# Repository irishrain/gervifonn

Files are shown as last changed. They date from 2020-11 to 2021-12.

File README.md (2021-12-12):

# gervifonn

The gervifonn is a device to access music stored in a digital music library by interacting with physical CD cases.
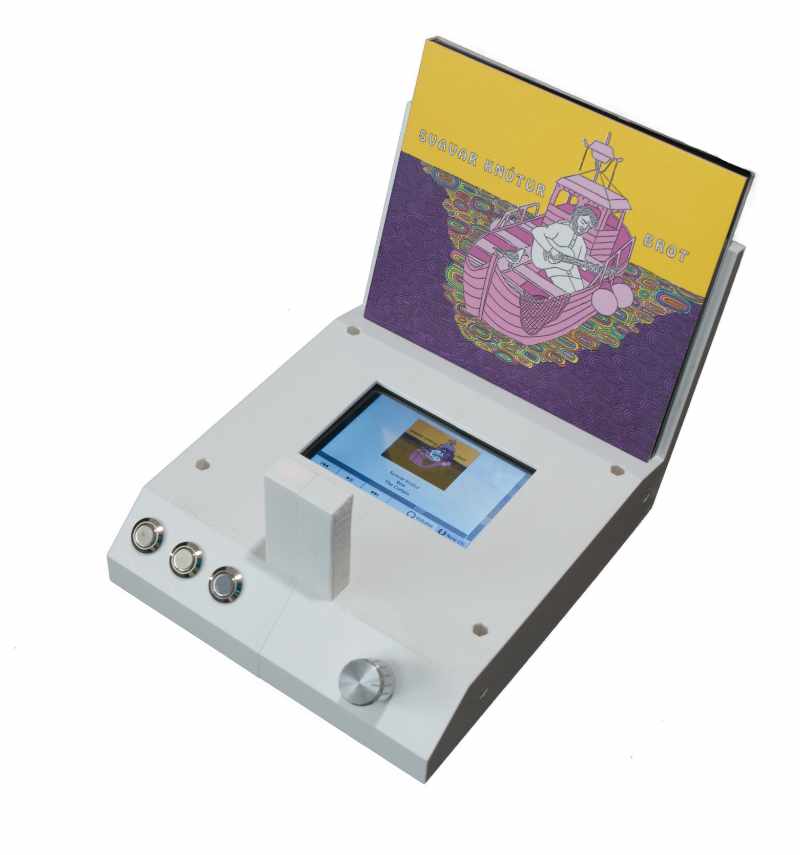
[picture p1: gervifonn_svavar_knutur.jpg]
Gervifonn Gervifonn with Brot by Svavar Knutur


## Features
The gervifonn displays the currently playing album. You can change the volume, pause playback or skip to the previous/next song. When you put a CD case onto the gervifonn and press the knob, it uses an AI to recognize the album you want to play.

### gervifonn in action

https://user-images.githubusercontent.com/74204581/131494693-2eaad112-3a38-4ad9-bd8d-b11cf11d26b1.mp4

https://user-images.githubusercontent.com/74204581/131494710-aeeac02b-b2e4-4ee5-975f-765dfd78c2d3.mp4

## Name
The name "gervifonn" derives from the icelandic words "gervigreind" (Artificial Intelligence) and "fónn" (Record Player).

## Assembly
See below for details of required parts and software. Assemble the gervifonn in the following order:
1. Install Raspberry Pi OS (Legacy) on micro SD card and put micro SD card into Raspberry Pi
2. Configure Rasberry Pi OS for automatic login, enable wifi, camera and ssh access and install the display drivers provided by the vendor
3. Install gervifonn software
4. Install pushbuttons, rotary encoder and knob
5. Connect camera cable to camera. Put together the right and left half of the case, fitting the camera into the camera holder and threading the power cord through the hole in the back of the case. Make a knot in the power cord as a strain relief. Use screws and nuts to secure
6. Use screws to fix Raspberry Pi on bottom part of the case
7. Connect the pushbuttons and the rotary encoder like this using the flat ribbon cable:
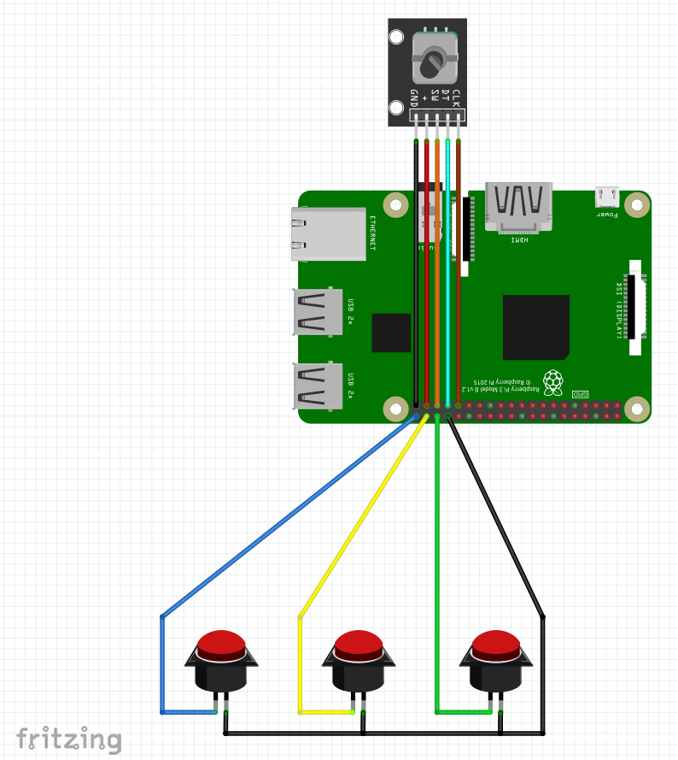
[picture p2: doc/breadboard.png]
Connections Breadboard view of required connections

6. Connect the camera cable to the Raspberry Pi and install display
7. Insert bottom part of case and secure with screws and nuts

## Components
### Case
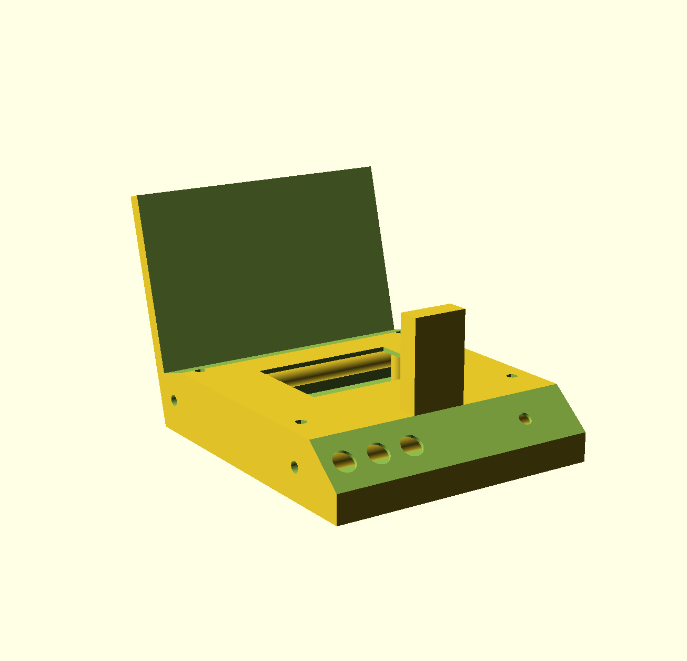
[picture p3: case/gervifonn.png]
Gervifonn case

The case is 3D printed. The [OpenSCAD](https://www.openscad.org/) source and generated STL files can be found under [case](case). The case is made from three parts, for assembly 12 M3 bolts and 8 M3 nuts are needed.
### Hardware
The heart of the gervifonn is a [Raspberry Pi 3 B+](https://www.raspberrypi.org/products/raspberry-pi-3-model-b-plus/).
Additionally the following parts were used (links to amazon.de, not sponsored):
* [Raspberry Pi Camera Revision 1.3](https://www.amazon.de/gp/product/B07CMXJLXR/) (use the long cable, not the 15cm one)
* [3.5 inch 320\*480 Resolution Touch Screen](https://www.amazon.de/gp/product/B01CNLYL1C/)
* [12mm pushbuttons](https://www.amazon.de/gp/product/B075YNQQ8J)
* [KY-040 Rotary Encoder](https://www.amazon.de/gp/product/B07CMVQHLT)
* [Knob for the Rotary Encoder](https://www.amazon.de/gp/product/B007JV6MAK)
* [10 Pin 2,54mm Pitch flat ribbon cable](https://www.amazon.de/gp/product/B07H9RQM5W/)
* A bit of extra wiring
* Micro-SD card
* Power supply for Raspberry Pi 3

### Software on the device
The gervifonn uses [Raspberry Pi OS](https://www.raspberrypi.org/software/) as a base.
The additional software running on the gervifonn can be found under [src](src). Install the requirements with `pip install -r requirements.txt` and place [src\gervifonn.desktop](src\gervifonn.desktop) into the /home/pi/.config/autostart/ directory of your raspberry. You might want to adapt the path to the gervifonn.py, the path to the music directory, the hostname of the [MPD](https://www.musicpd.org/) server, and the [Snapcast](https://github.com/badaix/snapcast) server and client if used.

### Software for training the AI
The AI-model needs to be trained on a more powerfull (linux) machine than a raspberry pi. A GPU with CUDA support is recommended, see [here](https://www.tensorflow.org/install/gpu#install_cuda_with_apt) for installation hints for the required libraries. Install the python libraries needed with `pip install -r training/requirements.txt`. To train the model use [training/train_gervifonn.py](training/train_gervifonn.py), with the path to your music folder and a folder with background images as arguments (details see below).
The resulting `gervifonn.tflite` model needs to be placed together with the generated `labels.txt` on your raspberry pi in the same folder as [src/gervifonn.py](src/gervifonn.py).

## Prerequesites
The gervifonn currently expects the following environment:
### Music library
The music library should be structured in the way [Jack](https://github.com/jack-cli-cd-ripper/jack) creates it, meaning one folder per Artist with subfolders for each album. Samplers are stored in the `Various` folder.

In addition, a cover image must be present in each folder, named `cover.png`. Optionally, you can place additional cover images in a subfolder called `gervifonn` inside each album. This will also be done by the gervifonn when you are using it. To simplify taking cover pictures of a bigger collection, you can use [src/gervifonn_capture_covers.py](src/gervifonn_capture_covers.py). Start it on the gervifonn, place the album on the gervifonn and press the leftmost button. It will take a picture in the correct format, display it and save it to the current folder. You can then put the next album on the gervifonn and press the leftmost button again. (Hint: use DISPLAY=:0 in front of the command when connected via ssh).

As albums with multiple CDs only have one cover, only place the `cover.png` in the first folder and create symlinks called `next` linking to the following CD.

To recap, here is an example folder structure:
~~~
Artist A
    Album 1
        gervifonn
            123.png
        cover.png
        Track X.ogg
        Track Y.ogg
        ...
    Album 2
        gervifonn
            456.png
            789.png
        cover.png
        Track I.ogg
        Track J.ogg
        ...
    ...
Artist B
    Album 1 CD 1
        gervifonn
            abc.png
        cover.png
        Track X.ogg
        ...
        next (symlink to ../Album 1 CD 2)
    Album 1 CD 2
        Track Y.ogg
        ...
...
~~~

### Music Player Daemon
The actual playback of the music is handled by the [Music Player Daemon](https://www.musicpd.org/). The MPD should be configured to read in your music library and should be reachable from the gervifonn (without authentification). If you don't have an extra machine, it should be fine to install the MPD on the gervifonn as well.

### Scnapcast
If the audio is streamed from the MPD via [Snapcast](https://github.com/badaix/snapcast) to the actual playback devices, the volume of one Snapcast client can be controlled by the gervifonn.

## Configuration
### Software on the device
gervifonn.py requires the following arguments:
| Argument | Description |
| --- | --- |
| -m MUSICFOLDER | Path to the music library |
| -n MPDSERVER | Hostname of the MPD server |

Additionally, the following optional arguments are supported:
| Argument | Description |
| --- | --- |
| -s SNAPCASTSERVER | Hostname of the snapcast server (that will be used to controll the volume). MPD server is used for volume if not given |
| -c SNAPCASTCLIENT | Name of the snapcast client (that will be controlled by the volume knob). MPD server is used for volume if not given |

### Software for training the AI
train_gervifonn.py requires the following arguments:
| Argument | Description |
| --- | --- |
| -m MUSICFOLDER | Path to the music library |
| -b BACKGROUNDFOLDER | Path to a folder containing random images to make the image recognition more robust |

Additionally, the following optional arguments are supported:
| Argument | Description |
| --- | --- |
| -s BATCHSIZE | Batchsize for training, affects GPU memory usage. Default: 2 |
| -e EPOCHS | Number of epochs for training. Default: 48 |
| -d | Enable dynamic GPU memory allocation |

## Detailed Usage
When using the gervifonn the display will show the current function of the buttons and the rotary knob. The three buttons on the left of the screen match the pushbuttons. On the right of the screen you can see what turning and pushing the knob will do.

* The default screen of the gervifonn will display the currently playing album cover, artist, album title and song title. The slider at the bottom shows playback position inside the song, the slider at the right the current volume:
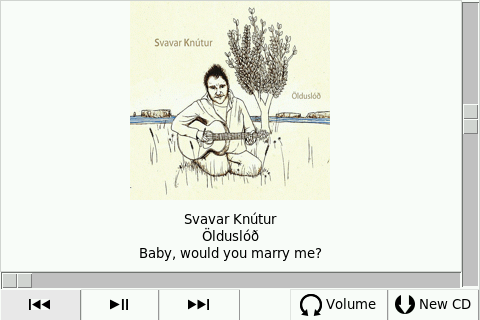
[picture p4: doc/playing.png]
Playing Screenshot of gervifonn when playing music


The three buttons can be used to pause/continue and switch songs. Turning the knob will change the volume. You can also use the slider below the cover to change the position in the song and the slider to the right to change the volume. To change the playing album, place the case on the gervifonn and press the knob.

* While the gervifonn is identifying the CD the display will show the picture taken by the camera:
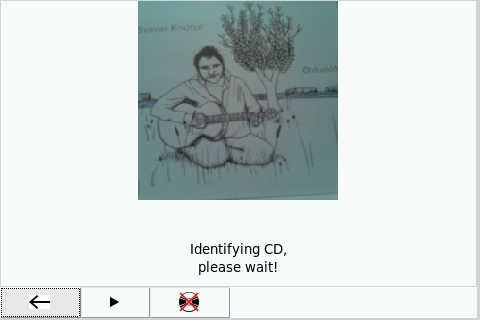
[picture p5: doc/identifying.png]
Identifying Screenshot of gervifonn when identifying CD


* When the gervifonn identified the CD it will show the cover, artist and title of the album:
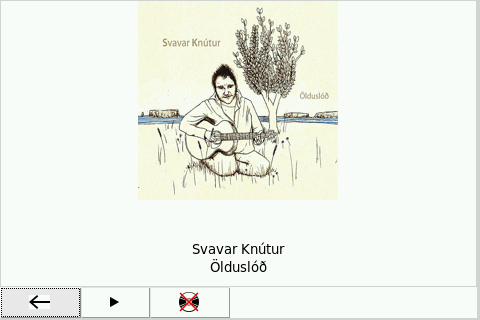
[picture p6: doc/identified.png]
Identified Screenshot of gervifonn when CD was identified


The left button cancels the change and goes back to the default screen. The middle button confirms that the CD was identified correctly and will start to play it. The right button can be used to select the correct album if the CD was not identified correctly.

* When the CD was not identified correctly, the display shows a list of all your albums:
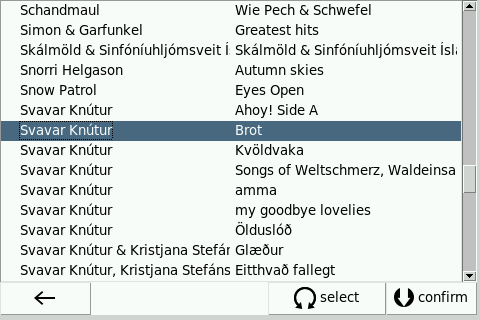
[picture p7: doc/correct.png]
Correct Screenshot of gervifonn when the identified CD needs to be corrected


The left button cancels the correction and goes back to the previous screen. You can either use the touchscreen or turn the knob to select the album you put on the gervifonn. Then you can press the knob to confirm your selection and start playback.

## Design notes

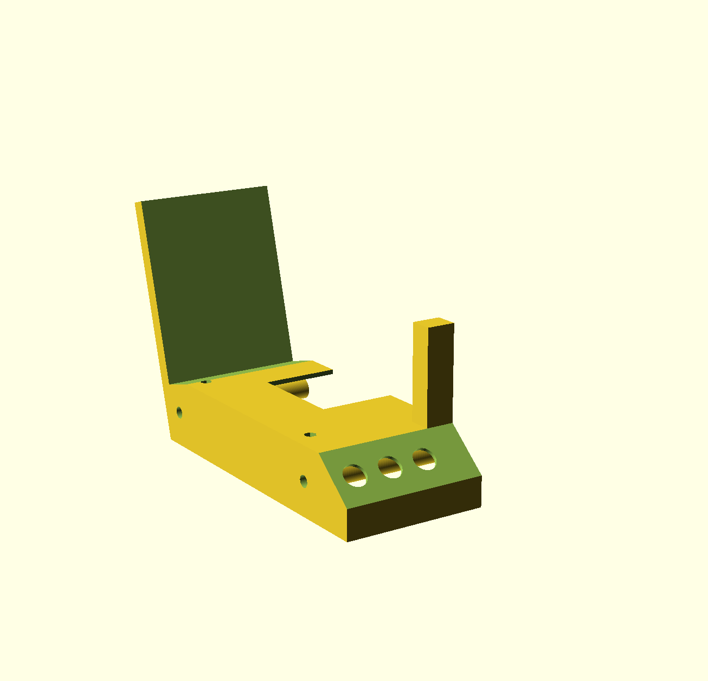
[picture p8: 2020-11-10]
case/gervifonn_left.png

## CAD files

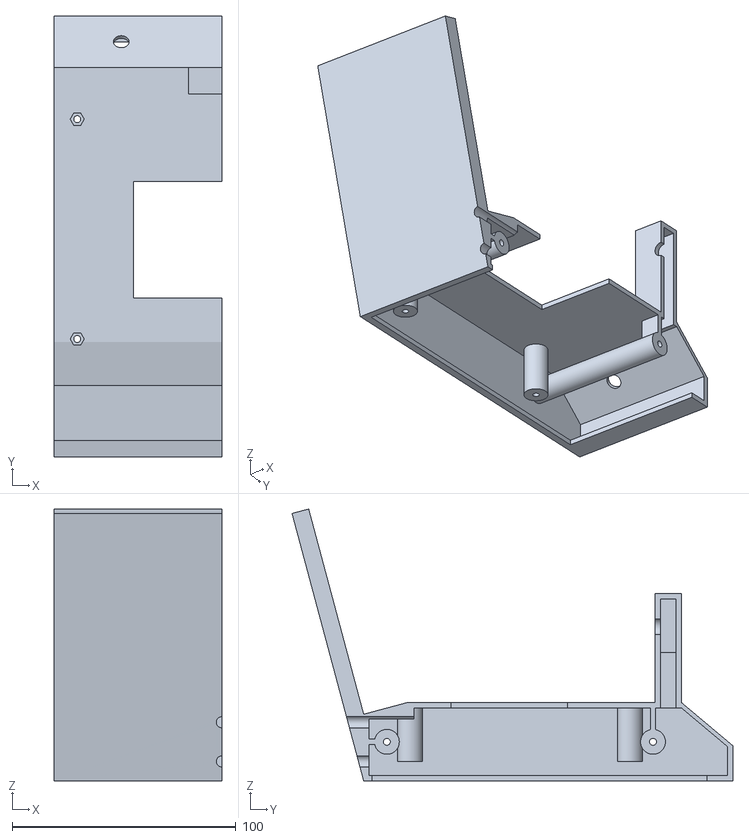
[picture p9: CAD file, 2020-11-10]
case/gervifonn_right.stl
75.0 x 197.0 x 121.5

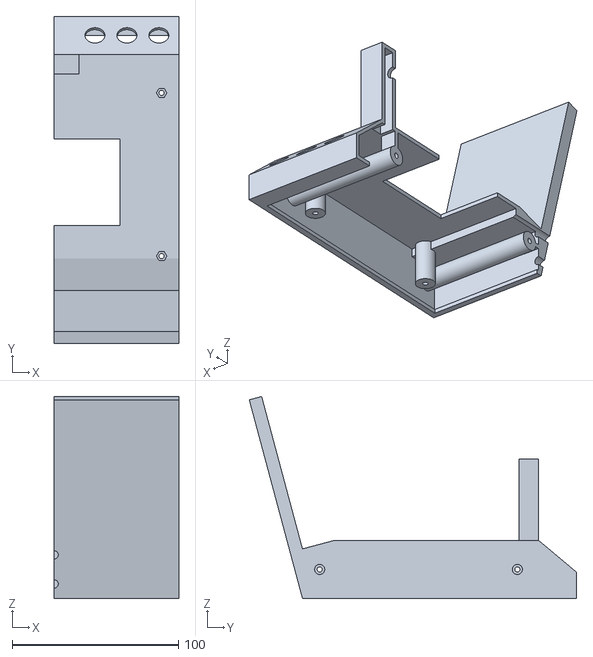
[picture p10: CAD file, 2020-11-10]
case/gervifonn_left.stl
75.0 x 197.0 x 121.5

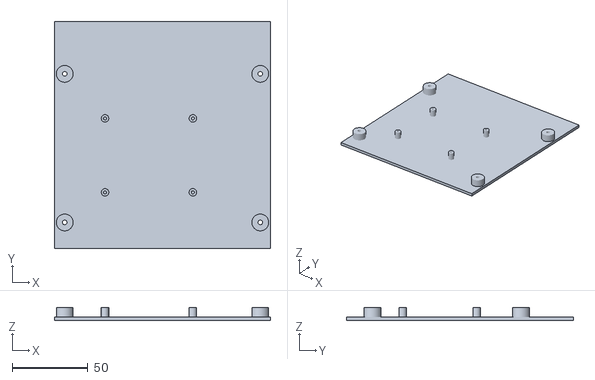
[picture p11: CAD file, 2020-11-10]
case/gervifonn_bottom.stl
142.8 x 149.8 x 8.61

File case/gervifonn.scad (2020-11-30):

// Copyright (C) 2020 Fabian Jansen

// This program is free software: you can redistribute it and/or modify
// it under the terms of the GNU General Public License as published by
// the Free Software Foundation, either version 3 of the License, or
// (at your option) any later version.

// This program is distributed in the hope that it will be useful,
// but WITHOUT ANY WARRANTY; without even the implied warranty of
// MERCHANTABILITY or FITNESS FOR A PARTICULAR PURPOSE.  See the
// GNU General Public License for more details.

// You should have received a copy of the GNU General Public License
// along with this program.  If not, see <http://www.gnu.org/licenses/>.


 $fa=0.25; // default minimum facet angle is now 0.5
 $fs=0.25; 

wall=2.4;
cdwidth=142;
cdheight=125;
cddepth=10;
cdangle=15;
basewidth=cdwidth+8;
baseheight=35;
basedepth=cdwidth;
supportstrength=baseheight*sin(cdangle);
supportheight=0.7*cdheight+baseheight/cos(cdangle);
camerawidth=25;
cameraheight=24;
cameraoffset=20;
camerastrength=7;
cameracable=17;
lensr=3.5;
lenspos=12.5;
panelangle=40;
panelsize=30;

buttonr=6;
dialr=3.5;
dialcylr=17/2;
dialcylh=17;

displaywidth=79;
displayheight=52;

piheight=24;
piholer=1.3;
pisupr=2.5;
pioffsetx=-2;
pioffsety=-2;
piholedistx=60.7-2*piholer;
piholedisty=51.5-2*piholer;
piholedistr=2.2+piholer;

piholderheight=baseheight-wall-piheight;

cabler=2.5;

nut_r=3.15; //Radius aussenkreis um Mutter
screw_r=1.55; //Radius Schraube
screwhead_r=3.05; //Radius Schraubenkopf


module cd() {
cdoffset=sin(cdangle)*cddepth*2;
translate([4,0,-cdoffset]){rotate([cdangle,0,0]){cube([cdwidth,cddepth,cdheight]);}}
    
}

module cd_angled() {
cdoffset=sin(cdangle)*cddepth*2;
translate([-1,0,-cdoffset]){rotate([cdangle,0,0]){cube([basewidth+2,cddepth*2,cdheight]);}}
}




module base() {
    translate([0,0,-baseheight]){
        cube([basewidth,basedepth,baseheight]);
        }
    
    }
module innerbase() {
    translate([wall,wall,-baseheight+wall]){
        difference() {
        cube([basewidth-2*wall,basedepth-2*wall,baseheight-2*wall]);
        translate([0,0,baseheight-2*wall-2*wall]) cube([basewidth-2*wall,2*cddepth,2*wall]);    
        }
    }
    }    
module cdsupport(){
    translate([0,0,-baseheight]){
    rotate([cdangle,0,0]){
 cube([basewidth,supportstrength,supportheight]);
}    }}
   
   
module camera(){
    translate([0.5*(basewidth-camerawidth)-wall,basedepth-camerastrength-2*wall,0]){
    cube([camerawidth+2*wall,camerastrength+2*wall,cameraheight+cameraoffset+2*wall]);
}}


module innercamera(){
    translate([0.5*(basewidth-camerawidth),basedepth-camerastrength-wall,cameraoffset+wall]){
    cube([camerawidth,camerastrength,cameraheight]);
}
  translate([0.5*(basewidth-cameracable),basedepth-camerastrength-wall,-2*wall]){
    cube([cameracable,camerastrength,cameraoffset+4*wall]);
}
   translate([0.5*basewidth,basedepth-camerastrength-3*wall,cameraoffset+wall+cameraheight-lenspos]){
    rotate([-90,0,0]){cylinder(h=3*wall,r=lensr);}}
}




module panel(){
    paneldepth=panelsize*cos(panelangle);
    translate([0,basedepth,0]){difference()
    { translate([0,0,-baseheight]){cube([basewidth,paneldepth,baseheight]);}
       translate([-1,0,0]){rotate([-panelangle,0,0]){cube([basewidth+2,panelsize,paneldepth+1]);}}
    }
}
}

module innerpanel(){
    paneldepth=panelsize*cos(panelangle);
    translate([0,basedepth,0]){difference()
    { translate([wall,-2*wall,-baseheight+wall]){cube([basewidth-2*wall,paneldepth+wall,baseheight-2*wall]);}
       translate([0,0,-wall]){rotate([-panelangle,0,0]){cube([basewidth,panelsize,paneldepth+1]);}}
    }
}
}



module buttons()
{
   dialcenter=0.25*(basewidth-(camerawidth+2*wall));
   buttonzero=0.5*basewidth+wall+0.5*camerawidth;
   buttonoffset=0.3333*(basewidth-buttonzero-wall); 
   translate([0,basedepth,0]){rotate([-panelangle,0,0]){
   translate([dialcenter,0.5*panelsize,-wall]){cylinder(h=2*wall, r=dialr);
       };
       %translate([dialcenter,0.5*panelsize,+wall]){cylinder(h=dialcylh, r=dialcylr);};
   translate([buttonzero+0.5*buttonoffset,0.5*panelsize,-wall]){cylinder(h=2*wall, r=buttonr);
       };
   translate([buttonzero+1.5*buttonoffset,0.5*panelsize,-wall]){cylinder(h=2*wall, r=buttonr);
       };
       translate([buttonzero+2.5*buttonoffset,0.5*panelsize,-wall]){cylinder(h=2*wall, r=buttonr);
       };   
  } }
}


module cablehole()
{
 translate([0.5*basewidth,-50,-0.25*baseheight]){rotate([-90,0,0]){cylinder(h=100,r=cabler);}}
translate([0.5*basewidth,-50,-0.75*baseheight]){rotate([-90,0,0]){cylinder(h=100,r=cabler);}}    
}

module holder() {
    difference(){
        cylinder(h=piholderheight-0.5*wall,r=pisupr);
        translate([0,0,wall]){cylinder(h=baseheight-wall-piheight,r=piholer-0.25);
        }}
    
    }
module piholder(){
   
   yoffset=0.5*(basedepth-camerastrength-2*wall-displayheight);
   xoffset=0.5*(basewidth-displaywidth);
translate([xoffset+pioffsetx+piholedistr,yoffset+pioffsety+piholedistr,-baseheight+0.5*wall]){holder();}
    translate([xoffset+pioffsetx+piholedistr+piholedistx,yoffset+pioffsety+piholedistr,-baseheight+0.5*wall]){holder();}
    translate([xoffset+pioffsetx+piholedistr,yoffset+pioffsety+piholedistr+piholedisty,-baseheight+0.5*wall]){holder();}
    translate([xoffset+pioffsetx+piholedistr+piholedistx,yoffset+pioffsety+piholedistr+piholedisty,-baseheight+0.5*wall]){holder();}
}

module display()
{
    translate([0.5*(basewidth-displaywidth),0.5*(basedepth-camerastrength-2*wall-displayheight),-baseheight+wall]){cube([displaywidth,displayheight,baseheight]);}
}

module screwholders()
{
    translate([0.5*wall,nut_r+3*wall,-0.5*baseheight]){
   rotate([0,90,0]){cylinder(r=nut_r+wall,h=basewidth-wall);}} 
    translate([0.5*wall,basedepth-nut_r-4*wall,-0.5*baseheight]){
   rotate([0,90,0]){cylinder(r=nut_r+wall,h=basewidth-wall);}}
   
   translate([nut_r+3*wall,2*nut_r+6*wall,-baseheight+0.5*wall]){
   cylinder(r=nut_r+wall,h=baseheight-wall);}

translate([nut_r+3*wall,basedepth-2*nut_r-7*wall,-baseheight+0.5*wall]){
   cylinder(r=nut_r+wall,h=baseheight-wall);}   

   translate([basewidth-nut_r-3*wall,2*nut_r+6*wall,-baseheight+0.5*wall]){
   cylinder(r=nut_r+wall,h=baseheight-wall);}
   
   
translate([basewidth-nut_r-3*wall,basedepth-2*nut_r-7*wall,-baseheight+0.5*wall]){
   cylinder(r=nut_r+wall,h=baseheight-wall);}

translate([0.5*basewidth-4*wall,-0.1,-0.5*baseheight-wall/2]) cube([8*wall,2.5*wall,wall]);

translate([0.5*basewidth-4*wall,basedepth-nut_r-4.5*wall,-wall+0.1-0.5*baseheight]) cube([8*wall,wall,0.5*baseheight]);   
   
}


module screwholes()
{
    translate([0.5*basewidth-10,nut_r+3*wall,-0.5*baseheight]){
   rotate([0,-90,0]){cylinder(r=nut_r,h=basewidth, $fn=6);}}
    translate([0,nut_r+3*wall,-0.5*baseheight]){
   rotate([0,90,0]){cylinder(r=screw_r,h=basewidth);}}
   translate([0.5*basewidth+10,nut_r+3*wall,-0.5*baseheight]){
   rotate([0,90,0]){cylinder(r=screwhead_r,h=basewidth);}}
   
   translate([0.5*basewidth-10,basedepth-nut_r-4*wall,-0.5*baseheight]){
   rotate([0,-90,0]){cylinder(r=nut_r,h=basewidth, $fn=6);}}
    translate([0,basedepth-nut_r-4*wall,-0.5*baseheight]){
   rotate([0,90,0]){cylinder(r=screw_r,h=basewidth);}}
   translate([0.5*basewidth+10,basedepth-nut_r-4*wall,-0.5*baseheight]){
   rotate([0,90,0]){cylinder(r=screwhead_r,h=basewidth);}}
   
     
   translate([nut_r+3*wall,2*nut_r+6*wall,-baseheight+piholderheight+wall]){
   cylinder(r=nut_r,h=baseheight, $fn=6);}
   translate([nut_r+3*wall,2*nut_r+6*wall,-2*baseheight+piholderheight-wall]){
   cylinder(r=screwhead_r,h=baseheight);}
   translate([nut_r+3*wall,2*nut_r+6*wall,-baseheight]){
   cylinder(r=screw_r,h=baseheight);}



   translate([nut_r+3*wall,basedepth-2*nut_r-7*wall,-baseheight+piholderheight+wall]){
   cylinder(r=nut_r,h=baseheight, $fn=6);}
   translate([nut_r+3*wall,basedepth-2*nut_r-7*wall,-2*baseheight+piholderheight-wall]){
   cylinder(r=screwhead_r,h=baseheight);}
   translate([nut_r+3*wall,basedepth-2*nut_r-7*wall,-baseheight]){
   cylinder(r=screw_r,h=baseheight);}


   translate([basewidth-nut_r-3*wall,2*nut_r+6*wall,-baseheight+piholderheight+wall]){
   cylinder(r=nut_r,h=baseheight, $fn=6);}
   translate([basewidth-nut_r-3*wall,2*nut_r+6*wall,-2*baseheight+piholderheight-wall]){
   cylinder(r=screwhead_r,h=baseheight);}
   translate([basewidth-nut_r-3*wall,2*nut_r+6*wall,-baseheight]){
   cylinder(r=screw_r,h=baseheight);}


   translate([basewidth-nut_r-3*wall,basedepth-2*nut_r-7*wall,-baseheight+piholderheight+wall]){
   cylinder(r=nut_r,h=baseheight, $fn=6);}
   translate([basewidth-nut_r-3*wall,basedepth-2*nut_r-7*wall,-2*baseheight+piholderheight-wall]){
   cylinder(r=screwhead_r,h=baseheight);}
   translate([basewidth-nut_r-3*wall,basedepth-2*nut_r-7*wall,-baseheight]){
   cylinder(r=screw_r,h=baseheight);}


}

module lefthalf() {
    translate([0.5*basewidth,-basedepth,-cdheight]){cube([basewidth,3*basedepth,3*cdheight]);};
}
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

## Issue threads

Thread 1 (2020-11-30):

Make paths, ... configurable

irishrain, 2020-11-30:
Currently the path to the music library, the path to the tflite file as well as the addresses of the MPD and Snapcast server and the snapcast client name are hardcoded.
Make this configurable.

irishrain, 2021-08-18:
Done

Closed 2021-08-18.

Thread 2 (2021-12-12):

train_gervifonn crashes when no on device pictures are present

irishrain, 2021-12-12:
When no pictures are found in the "gervifonn" subfolders of the music album directories, the valgenerator cannot be initialized as the to_categorical call crashes.

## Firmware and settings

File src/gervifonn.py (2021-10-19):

#!/usr/bin/env python3

# Copyright (C) 2020 Fabian Jansen

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
import RPi.GPIO as GPIO
import time
from tkinter import *
from tkinter import ttk
from PIL import Image, ImageTk
from mpd import MPDClient
from picamera.array import PiRGBArray
from picamera import PiCamera
import numpy as np
import tflite_runtime.interpreter as tflite
import asyncio
import snapcast.control
import os
import argparse


class album:
    def __init__(self, artist, albumtitle, imagefile, music, musicdirectory):
        self.artist = artist
        self.album = albumtitle
        self.imagefile = imagefile
        self.image = False
        if os.path.islink('/'.join((musicdirectory, artist, albumtitle, 'next'))):
            target = os.readlink('/'.join((musicdirectory, artist, albumtitle, 'next'))).split('/')[1]
            music[(artist, albumtitle)] = album(artist, target, imagefile, music, musicdirectory)

    def get_image(self):
        if not self.image:
            im = Image.open(self.imagefile)
            im.thumbnail((200, 200))
            self.image = ImageTk.PhotoImage(im)
        return self.image


class gervifonn:
    def __init__(self, musicdirectory, datadirectory, mpdserver, snapcastserver,  snapcastclient):
        self.musicdirectory = musicdirectory
        self.datadirectory = datadirectory
        self.state = 'default'
        self.initgpio()
        self.inittk()
        self.inittf()
        self.initcamera()
        self.artist = ''
        self.album = ''
        self.title = ''
        self.initmusic()
        self.initmpc(mpdserver)
        if (snapcastserver is None or snapcastclient is None):
            self.volupdate = 0
            self.setvol=self.setvol_mpd
            self.getvol=self.getvol_mpd
        else:
            self.initsnapcast(snapcastserver, snapcastclient)
            self.setvol=self.setvol_snap
            self.getvol=self.getvol_snap
        self.initwidgets()
        self.showdefaultwindow()
        self.update(False)
        self.root.after(1000, self.update)
        self.root.mainloop()

    def initsnapcast(self, snapcastserver, snapcastclient):
        self.snaploop = asyncio.get_event_loop()
        self.snapserver = self.snaploop.run_until_complete(snapcast.control.create_server(self.snaploop,  snapcastserver))
        for client in self.snapserver.clients:
            if client.friendly_name == snapcastclient:
                self.snapclientid = client.identifier
        self.volupdate = 0

    def inittf(self):
        print('init tf')
        self.imgsize = 224
        self.interpreter = tflite.Interpreter(model_path=self.datadirectory+"/gervifonn.tflite")
        self.interpreter.allocate_tensors()
        self.input_details = self.interpreter.get_input_details()
        self.output_details = self.interpreter.get_output_details()

    def initcamera(self):
        print('init camera')
        self.camera = PiCamera()
        self.camera.resolution = (self.imgsize, self.imgsize)

    def initmpc(self, server):
        print('init mpd')
        self.mpc = MPDClient()
        self.mpc.connect(server, 6600)
        self.timeupdate = 0

    def initmusic(self):
        print('init music')
        self.music = {}
        for row in open(self.datadirectory+"/labels.txt"):
            # unpack the row and update the labels dictionary
            (classID, label) = row.strip().split(maxsplit=1)
            tartist, talbum = label.strip().split('/')
            self.music[int(classID)] = album(tartist, talbum, '/'.join((self.musicdirectory, tartist, talbum, 'cover.png')), self.music,  self.musicdirectory)

    def inittk(self):
        print('init tk')
        self.root = Tk()
        self.style = ttk.Style()
        self.style.configure('TButton', background='white')
        self.style.configure('TLabel', background='white')
        self.style.configure('TFrame', background='white')
        self.root.attributes("-fullscreen", True)
        self.content = ttk.Frame(self.root)
        self.coverimage = ImageTk.PhotoImage(Image.new("RGB", (20, 20), "white"))

    def initwidgets(self):
        print('init widgets')
        self.covercanvas = Canvas(self.content, width=460, height=270, background="white")
        self.canvascoverimage = self.covercanvas.create_image(0, 0, image=self.coverimage, anchor='center')
        self.canvasartist = self.covercanvas.create_text(0, 0, text=self.artist, anchor='center', font='TkMenuFont', fill='black')
        self.canvasalbum = self.covercanvas.create_text(0, 0, text=self.album, anchor='center', font='TkMenuFont', fill='black')
        self.canvastitle = self.covercanvas.create_text(0, 0, text=self.title, anchor='center', font='TkMenuFont', fill='black')
        self.timescale = ttk.Scale(self.content, orient=HORIZONTAL, length=460, from_=0.0, to=100.0, command=self.settime)
        self.volumescale = ttk.Scale(self.content, orient=VERTICAL, length=285, from_=100.0, to=0.0, command=self.setvol)
        self.previmage = PhotoImage(file=self.datadirectory+'/prev.png')
        self.prevbutton = ttk.Button(self.content, image=self.previmage, command=self.leftbutton)
        self.prevbutton.image = self.previmage
        self.playpauseimage = PhotoImage(file=self.datadirectory+'/playpause.png')
        self.playpausebutton = ttk.Button(self.content, image=self.playpauseimage, command=self.middlebutton)
        self.playpausebutton.image = self.playpauseimage
        self.nextimage = PhotoImage(file=self.datadirectory+'/next.png')
        self.nextbutton = ttk.Button(self.content, image=self.nextimage, command=self.rightbutton)
        self.nextbutton.image = self.nextimage

        self.rotateimage = PhotoImage(file=self.datadirectory+'/rotate.png')
        self.volbutton = ttk.Button(self.content, text='Volume', image=self.rotateimage, compound='left', width=7)
        self.volbutton.image = self.rotateimage
        self.pushimage = PhotoImage(file=self.datadirectory+'/push.png')
        self.newbutton = ttk.Button(self.content, text='New CD', image=self.pushimage, compound='left', width=7, command=self.wheelclick)
        self.newbutton.image = self.pushimage
        self.backimage = PhotoImage(file=self.datadirectory+'/back.png')
        self.backbutton = ttk.Button(self.content, image=self.backimage, command=self.leftbutton)
        self.backbutton.image = self.backimage
        self.playimage = PhotoImage(file=self.datadirectory+'/play.png')
        self.playbutton = ttk.Button(self.content, image=self.playimage, command=self.middlebutton)
        self.playbutton.image = self.playimage
        self.wrongimage = PhotoImage(file=self.datadirectory+'/wrong.png')
        self.wrongbutton = ttk.Button(self.content, image=self.wrongimage, command=self.rightbutton)
        self.wrongbutton.image = self.wrongimage

        self.albumtree = ttk.Treeview(self.content, columns=('Album'), height=14, show="tree", selectmode="browse")
        self.albumtree.column("#0", width=int(460/2), stretch=NO)
        self.albumtree.column("Album", width=int(460/2), stretch=NO)
        _, talbums = zip(*sorted(self.music.items(), key=lambda x: (x[1].artist, x[1].album)))
        for talbum in talbums:
            self.albumtree.insert('', 'end', text=talbum.artist, values=(talbum.album, ))
        self.scrollbar = ttk.Scrollbar(self.content, orient="vertical", command=self.albumtree.yview)
        self.albumtree.configure(yscrollcommand=self.scrollbar.set)
        self.selectbutton = ttk.Button(self.content, text='select', image=self.rotateimage, compound='left', width=7)
        self.selectbutton.image = self.rotateimage
        self.confirmbutton = ttk.Button(self.content, text='confirm', image=self.pushimage, compound='left', width=7, command=self.wheelclick)
        self.confirmbutton.image = self.pushimage
        self.content.grid(column=0, row=0)

    def showdefaultwindow(self):
        cw = 460
        ch = 270
        self.covercanvas['width'] = cw
        self.covercanvas['height'] = ch
        self.covercanvas.coords(self.canvascoverimage, cw/2, 100)
        self.covercanvas.coords(self.canvasartist, cw/2, ch*13/16)
        self.covercanvas.coords(self.canvasalbum, cw/2, ch*14/16)
        self.covercanvas.coords(self.canvastitle, cw/2, ch*15/16)
        self.covercanvas.itemconfigure(self.canvascoverimage, state='normal')
        self.covercanvas.itemconfigure(self.canvasartist, state='normal')
        self.covercanvas.itemconfigure(self.canvasalbum, state='normal')
        self.covercanvas.itemconfigure(self.canvastitle, state='normal')
        self.covercanvas.grid(column=0, row=0, columnspan=7, rowspan=3)
        self.timescale.grid(column=0, row=3, columnspan=7, sticky=(S))
        self.volumescale.grid(column=7, row=0, rowspan=4, sticky=(E))
        self.prevbutton.grid(column=0, row=4, sticky=(N, S, E, W))
        self.playpausebutton.grid(column=1, row=4, sticky=(N, S, E, W))
        self.nextbutton.grid(column=2, row=4, sticky=(N, S, E, W))
        self.volbutton.grid(column=4, row=4, columnspan=2, sticky=(N, S, E, W))
        self.newbutton.grid(column=6, row=4, columnspan=2, sticky=(N, S, E, W))

    def hidedefaultwindow(self):
        self.covercanvas.itemconfigure(self.canvascoverimage, state='hidden')
        self.covercanvas.itemconfigure(self.canvasartist, state='hidden')
        self.covercanvas.itemconfigure(self.canvasalbum, state='hidden')
        self.covercanvas.itemconfigure(self.canvastitle, state='hidden')
        self.covercanvas.grid_forget()
        self.timescale.grid_forget()
        self.volumescale.grid_forget()
        self.prevbutton.grid_forget()
        self.playpausebutton.grid_forget()
        self.nextbutton.grid_forget()
        self.volbutton.grid_forget()
        self.newbutton.grid_forget()

    def showvalidatewindow(self):
        cw = 475
        ch = 285
        self.covercanvas['width'] = cw
        self.covercanvas['height'] = ch
        self.covercanvas.coords(self.canvascoverimage, cw/2, 100)
        self.covercanvas.coords(self.canvasartist, cw/2, ch*14/16)
        self.covercanvas.coords(self.canvasalbum, cw/2, ch*15/16)
        self.covercanvas.itemconfigure(self.canvascoverimage, state='normal')
        self.covercanvas.itemconfigure(self.canvasartist, state='normal')
        self.covercanvas.itemconfigure(self.canvasalbum, state='normal')
        self.covercanvas.grid(column=0, row=0, columnspan=8, rowspan=3)
        self.backbutton.grid(column=0, row=4, sticky=(N, S, E, W))
        self.playbutton.grid(column=1, row=4, sticky=(N, S, E, W))
        self.wrongbutton.grid(column=2, row=4, sticky=(N, S, E, W))

    def hidevalidatewindow(self):
        self.covercanvas.itemconfigure(self.canvascoverimage, state='hidden')
        self.covercanvas.itemconfigure(self.canvasartist, state='hidden')
        self.covercanvas.itemconfigure(self.canvasalbum, state='hidden')
        self.covercanvas.grid_forget()

        self.backbutton.grid_forget()
        self.playbutton.grid_forget()
        self.wrongbutton.grid_forget()

    def showselectwindow(self):
        cid = self.albumtree.get_children()[0]
        self.albumtree.focus(cid)
        self.albumtree.selection_set(cid)
        self.albumtree.grid(column=0, row=0, columnspan=7, rowspan=3)
        self.scrollbar.grid(column=7, row=0, rowspan=4, sticky=(N, S, E))

        self.backbutton.grid(column=0, row=4, sticky=(N, S, E, W))

        self.selectbutton.grid(column=4, row=4, columnspan=2, sticky=(N, S, E, W))
        self.confirmbutton.grid(column=6, row=4, columnspan=2, sticky=(N, S, E, W))

    def hideselectwindow(self):
        self.albumtree.grid_forget()
        self.scrollbar.grid_forget()

        self.backbutton.grid_forget()

        self.selectbutton.grid_forget()
        self.confirmbutton.grid_forget()

    def settime(self, perc):
        if self.timeupdate == 0:
            status = self.mpc.status()
            if 'state' in status and 'duration' in status and status['state'] in ['pause', 'play']:
                newtime = float(status['duration'])*float(perc)/100
                print('seek to', newtime)
                self.mpc.seekcur(newtime)
        else:
            self.timeupdate = 0

    def setvol_snap(self, perc):
        if self.volupdate == 0:
            self.volume = float(perc)
            self.snaploop.run_until_complete(self.snapserver.client_volume(self.snapclientid, {'percent': self.volume, 'muted': False}))
        else:
            self.volupdate = 0

    def setvol_mpd(self, perc):
        if self.volupdate == 0:
            self.volume = float(perc)
            self.mpc.setvol(int(self.volume))
        else:
            self.volupdate = 0

    def getvol_snap(self):
        return self.snaploop.run_until_complete(self.snapserver.client_status(self.snapclientid))['config']['volume']['percent']

    def getvol_mpd(self):
        status = self.mpc.status()
        if 'volume' in status:
            return int(status['volume'])
        else:
            return 0

    def update(self, *args):
        status = self.mpc.status()
        if 'state' in status and status['state'] in ['pause', 'play']:
            self.timeupdate = 1
            if 'duration' in status and 'elapsed' in status:
                self.timescale.set(100*float(status['elapsed'])/float(status['duration']))
            else:
                self.timescale.set(0)
            song = self.mpc.currentsong()
            if 'artist' in song:
                self.artist = song['artist']
            else:
                self.artist = ''
            if 'album' in song:
                self.album = song['album']
            else:
                self.album = ''
            if 'title' in song:
                self.title = song['title']
            else:
                self.title = ''
            talbum = self.getalbum(self.artist, self.album)
            if talbum >= 0:
                self.coverimage = self.music[talbum].get_image()
            else:
                self.coverimage = ImageTk.PhotoImage(Image.new("RGB", (20, 20), "white"))
        else:
            self.timescale.set(0)
            self.artist = ''
            self.album = ''
            self.title = ''
            self.coverimage = ImageTk.PhotoImage(Image.new("RGB", (20, 20), "white"))
        self.volume = self.getvol()
        self.volupdate = 1
        self.volumescale.set(self.volume)
        if self.state == 'default':
            self.covercanvas.itemconfigure(self.canvascoverimage, image=self.coverimage)
            self.covercanvas.itemconfigure(self.canvasartist, text=self.artist)
            self.covercanvas.itemconfigure(self.canvasalbum, text=self.album)
            self.covercanvas.itemconfigure(self.canvastitle, text=self.title)
        if not (len(args) == 1 and args[0] is False):
            self.root.after(1000, self.update)

    def getalbum(self, artist, album):
        matches = [talbum for talbum in self.music if self.music[talbum].artist == artist and self.music[talbum].album == album]
        if len(matches) > 0:
            return matches[0]
        else:
            matches = [talbum for talbum in self.music if self.music[talbum].artist == 'Various' and self.music[talbum].album == album]
            if len(matches) > 0:
                return matches[0]
            else:
                return -1

    def initgpio(self):
        print('init gpio')
        GPIO.setmode(GPIO.BCM)
        GPIO.setup(26, GPIO.OUT)
        GPIO.output(26, GPIO.HIGH)
        GPIO.setup(16, GPIO.IN, pull_up_down=GPIO.PUD_UP)
        GPIO.setup(20, GPIO.IN, pull_up_down=GPIO.PUD_UP)
        GPIO.setup(21, GPIO.IN, pull_up_down=GPIO.PUD_UP)
        GPIO.setup(6, GPIO.IN, pull_up_down=GPIO.PUD_UP)
        GPIO.setup(13, GPIO.IN, pull_up_down=GPIO.PUD_UP)
        GPIO.setup(19, GPIO.IN, pull_up_down=GPIO.PUD_UP)
        GPIO.add_event_detect(6, GPIO.FALLING, callback=self.wheelcallback, bouncetime=200)
        GPIO.add_event_detect(19, GPIO.FALLING, callback=self.wheelclick, bouncetime=400)
        GPIO.add_event_detect(16, GPIO.FALLING, callback=self.rightbutton, bouncetime=400)
        GPIO.add_event_detect(20, GPIO.FALLING, callback=self.middlebutton, bouncetime=400)
        GPIO.add_event_detect(21, GPIO.FALLING, callback=self.leftbutton, bouncetime=400)

    def wheelcallback(self, *args):
        if GPIO.input(6) == 0:
            self.wheelturn(GPIO.input(13))

    def leftbutton(self, *args):
        print('left')
        if self.state == 'default':
            self.mpc.previous()
        elif self.state == 'validate':
            self.state = 'busy'
            self.hidevalidatewindow()
            self.showdefaultwindow()
            self.state = 'default'
        elif self.state == 'select':
            self.state = 'busy'
            self.hideselectwindow()
            self.showvalidatewindow()
            self.state = 'validate'

    def middlebutton(self, *args):
        print('middle')
        if self.state == 'default':
            self.mpc.pause()
        elif self.state == 'validate':
            self.state = 'busy'
            self.hidevalidatewindow()
            self.mpc.clear()
            artist = self.recognized.artist
            album = self.recognized.album
            self.mpc.searchadd("file", "{}/{}/".format(artist, album))
            while (artist, album) in self.music:
                nalbum = self.music[(artist, album)]
                artist = nalbum.artist
                album = nalbum.album
                self.mpc.searchadd("file", "{}/{}/".format(artist, album))
            self.mpc.play()
            filename = '/'.join((self.musicdirectory, self.recognized.artist, self.recognized.album, 'gervifonn', str(time.time())+'.png'))
            self.videoimage.save(filename)
            self.state = 'default'
            self.update()
            self.showdefaultwindow()

    def rightbutton(self, *args):
        print('right')
        if self.state == 'default':
            self.mpc.next()
        elif self.state == 'validate':
            self.state = 'busy'
            self.hidevalidatewindow()
            self.showselectwindow()
            self.state = 'select'

    def wheelclick(self, *args):
        print('click')
        if self.state == 'default':
            self.state = 'busy'
            self.hidedefaultwindow()
            rawCapture = PiRGBArray(self.camera)
            self.camera.capture(rawCapture, format="rgb")
            self.videoimage = Image.fromarray(rawCapture.array)
            self.capturedimage = self.videoimage.resize((200, 200))
            self.capturedimage = ImageTk.PhotoImage(self.capturedimage)
            self.covercanvas.itemconfigure(self.canvascoverimage, image=self.capturedimage)
            self.covercanvas.itemconfigure(self.canvasartist, text='Identifying CD,')
            self.covercanvas.itemconfigure(self.canvasalbum, text='please wait!')
            self.showvalidatewindow()

            videoframe = np.asarray(rawCapture.array[:self.imgsize, :self.imgsize, :], dtype=np.float32)
            videoframe = np.expand_dims(videoframe, axis=0)
            self.interpreter.set_tensor(self.input_details[0]['index'], videoframe)
            self.interpreter.invoke()
            preds = self.interpreter.get_tensor(self.output_details[0]['index'])
            scores = []
            for (i, pred) in enumerate(preds[0, :]):
                scores.append([self.music[i], pred])
            scores.sort(key=lambda tup: -tup[1])
            self.recognized = scores[0][0]
            self.covercanvas.itemconfigure(self.canvascoverimage, image=self.recognized.get_image())
            self.covercanvas.itemconfigure(self.canvasartist, text=self.recognized.artist)
            self.covercanvas.itemconfigure(self.canvasalbum, text=self.recognized.album)
            self.state = 'validate'
        elif self.state == 'select':
            self.state = 'busy'
            ciid = self.albumtree.focus()
            selected = self.albumtree.item(ciid)
            artist = selected['text']
            album = selected['values'][0]
            self.hideselectwindow()
            self.mpc.clear()
            self.mpc.searchadd("file", "{}/{}/".format(artist, album))
            while (artist, album) in self.music:
                nalbum = self.music[(artist, album)]
                artist = nalbum.artist
                album = nalbum.album
                self.mpc.searchadd("file", "{}/{}/".format(artist, album))
            self.mpc.play()
            filename = '/'.join((self.musicdirectory, artist, album, 'gervifonn', str(time.time())+'.png'))
            self.videoimage.save(filename)
            self.state = 'default'
            self.update(False)
            self.showdefaultwindow()

    def wheelturn(self, direct):
        if direct == 0:
            print('leftturn')
            if self.state == 'default':
                self.setvol(max(self.volume-5, 0))
            elif self.state == 'select':
                ciid = self.albumtree.focus()
                previd = self.albumtree.prev(ciid)
                if not previd == '':
                    self.albumtree.focus(previd)
                    self.albumtree.selection_set(previd)
                    self.albumtree.see(previd)
        else:
            print('rightturn')
            if self.state == 'default':
                self.setvol(min(self.volume+5, 100))
            elif self.state == 'select':
                ciid = self.albumtree.focus()
                nextid = self.albumtree.next(ciid)
                if not nextid == '':
                    self.albumtree.focus(nextid)
                    self.albumtree.selection_set(nextid)
                    self.albumtree.see(nextid)

    def __del__(self):
        self.mpc.close()
        GPIO.cleanup()
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

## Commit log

2020-11-10 Added case OpenSCAD file, STL files and pictures
    [gervifonn.scad, gervifonn_bottom.stl, gervifonn_left.stl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]
2020-11-10 Updated README.md, added case information.
2020-11-10 List of materials
2020-11-30 Added button symbols
2020-11-30 Added copyright notice to .scad
    [gervifonn.scad]
2021-03-06 Fixed volume update variable name
    [gervifonn.py]
2021-03-27 No crash when song information not available
    [gervifonn.py]
2021-03-27 No crash when duration not available
    [gervifonn.py]
2021-08-31 Added missing licence text
    [gervifonn_capture_covers.py]
2021-11-03 Update README.md
    Hint about cable length
2021-12-12 Use Raspberry Pi OS (Legacy), enable camera, DISPLAY=:0
